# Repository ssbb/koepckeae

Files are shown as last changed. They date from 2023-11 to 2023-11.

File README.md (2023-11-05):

# koepckeae

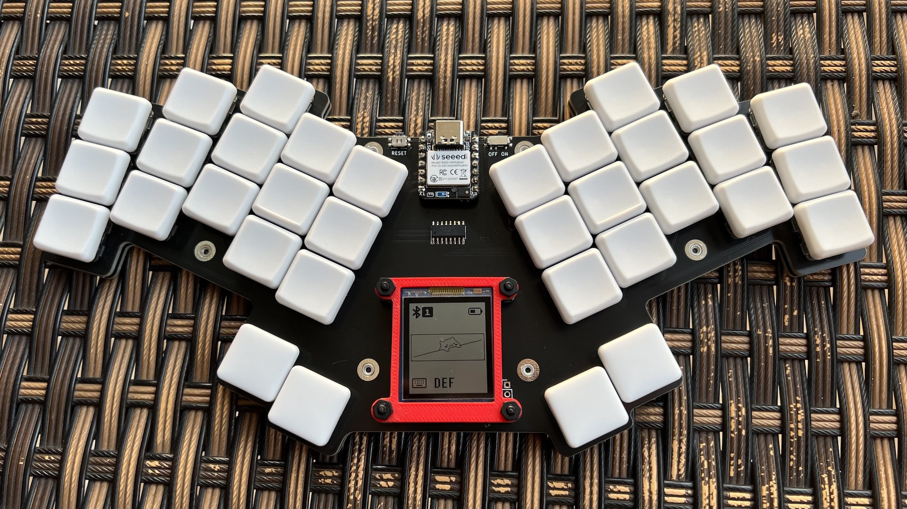
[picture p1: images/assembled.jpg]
PCB


koepckeae is a 34-key unibody split keyboard higihly inspired by Pete Johanson's [Zaphod Lite](https://gitlab.com/lpgalaxy/zaphod/-/tree/main), featuring hotswap support, splay, and spaced out thumbs.

## BOM

| Qty | Name | Source |
|-----|---|---|
| 1 | PCB | [gerbers](pcb/choc/koepckeae_gerbers.zip) |
| 1 | XIAO nRF52840 | [Digikey](https://www.digikey.com/en/products/detail/seeed-technology-co-ltd/102010448/16652893) |
| 1 | 74HC595D shift register (SOIC-16) | [LCSC](https://www.lcsc.com/product-detail/Shifting-Register_Nexperia-74HC595D-118_C5947.html) |
| 1 | PCM12 power switch | [LCSC](https://www.lcsc.com/product-detail/Slide-Switches_C-K-PCM12SMTR_C221841.html) |
| 1 | Panasonic EVQPUC02K reset button | [LCSC](https://www.lcsc.com/product-detail/_PANASONIC-_C79174.html) |
| 2 | 1x1 Mill-Max Spring Loaded Header (0906-2-15-20-75-14-11-0) | [Digikey](https://www.digikey.com/en/products/detail/mill-max-manufacturing-corp/0906-2-15-20-75-14-11-0/1147050)  |
| 2 | 1x7 Mill-Max Header (310-43-107-41-001000) | [Digikey](https://www.digikey.com/en/products/detail/mill-max-manufacturing-corp/310-43-107-41-001000/1212181) |
| 1 | JST PH-2.0 battery socket | [LCSC](https://www.lcsc.com/product-detail/Wire-To-Board-Wire-To-Wire-Connector_JST-S2B-PH-K-S-LF-SN_C173752.html) |
| 1 | 702025 300 mAh battery | |
| 34  | 1N4148W diode | [LCSC](https://www.lcsc.com/product-detail/Switching-Diode_MDD-Microdiode-Electronics-1N4148W_C84367.html) |
| 34  | Kailh Choc hotswap sockets | [Aliexpress](https://aliexpress.com/item/33023283633.html?sku_id=10000000883911874) |

Max battery dimensions are 29mm x 21mm x 8mm. Ideally get a battery with JST connector but double check polarity on PCB.

### Plate case

| Qty | Name | Source |
|-----|---|---|
| 1 | Bottom Plate | [gerbers](mechanical/bottom-plate/bottom_plate_gerbers.zip) |
| 8 | Solder Nuts  | [LCSC](https://www.lcsc.com/product-detail/_Sinhoo-_C2916384.html) |
| 8 | M2x5 screws  | |

### Display

| Qty | Name | Source |
|-----|---|---|
| 1 | Adafruit Sharp Memory Display | [Adafruit](https://www.adafruit.com/product/3502) |
| 1 | 1x5 Mill-Max Spring Loaded Header (825-22-005-10-001101) | [Digikey](https://www.digikey.com/en/products/detail/mill-max-manufacturing-corp/825-22-005-10-001101/6149696) |
| 4 | M2.5x6 male-female nylon standoff | [Aliexpress](https://aliexpress.com/item/32871403400.html?sku_id=10000002420611426) |
| 4 | M2.5 nylon nut | [Aliexpress](https://aliexpress.com/item/32868992270.html?sku_id=10000010058105677) |
| 4 | M2.5x6 nylon screw | [Aliexpress](https://aliexpress.com/item/32870030598.html?sku_id=10000002668418327) |

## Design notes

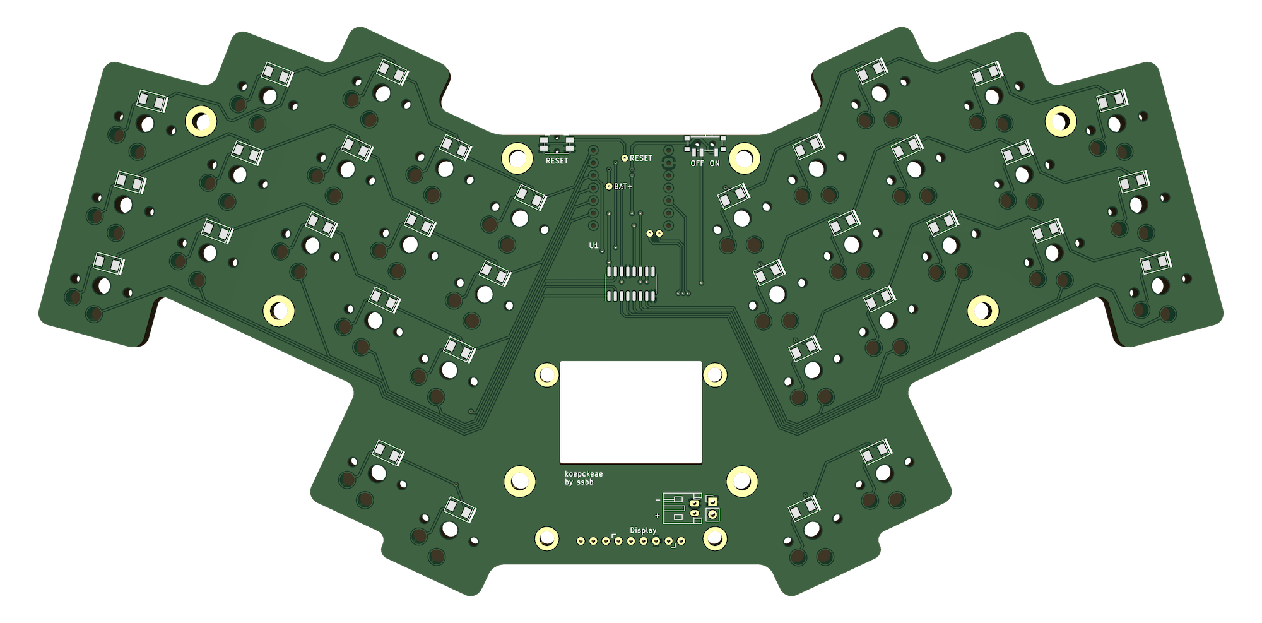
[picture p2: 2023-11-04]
images/pcb.png

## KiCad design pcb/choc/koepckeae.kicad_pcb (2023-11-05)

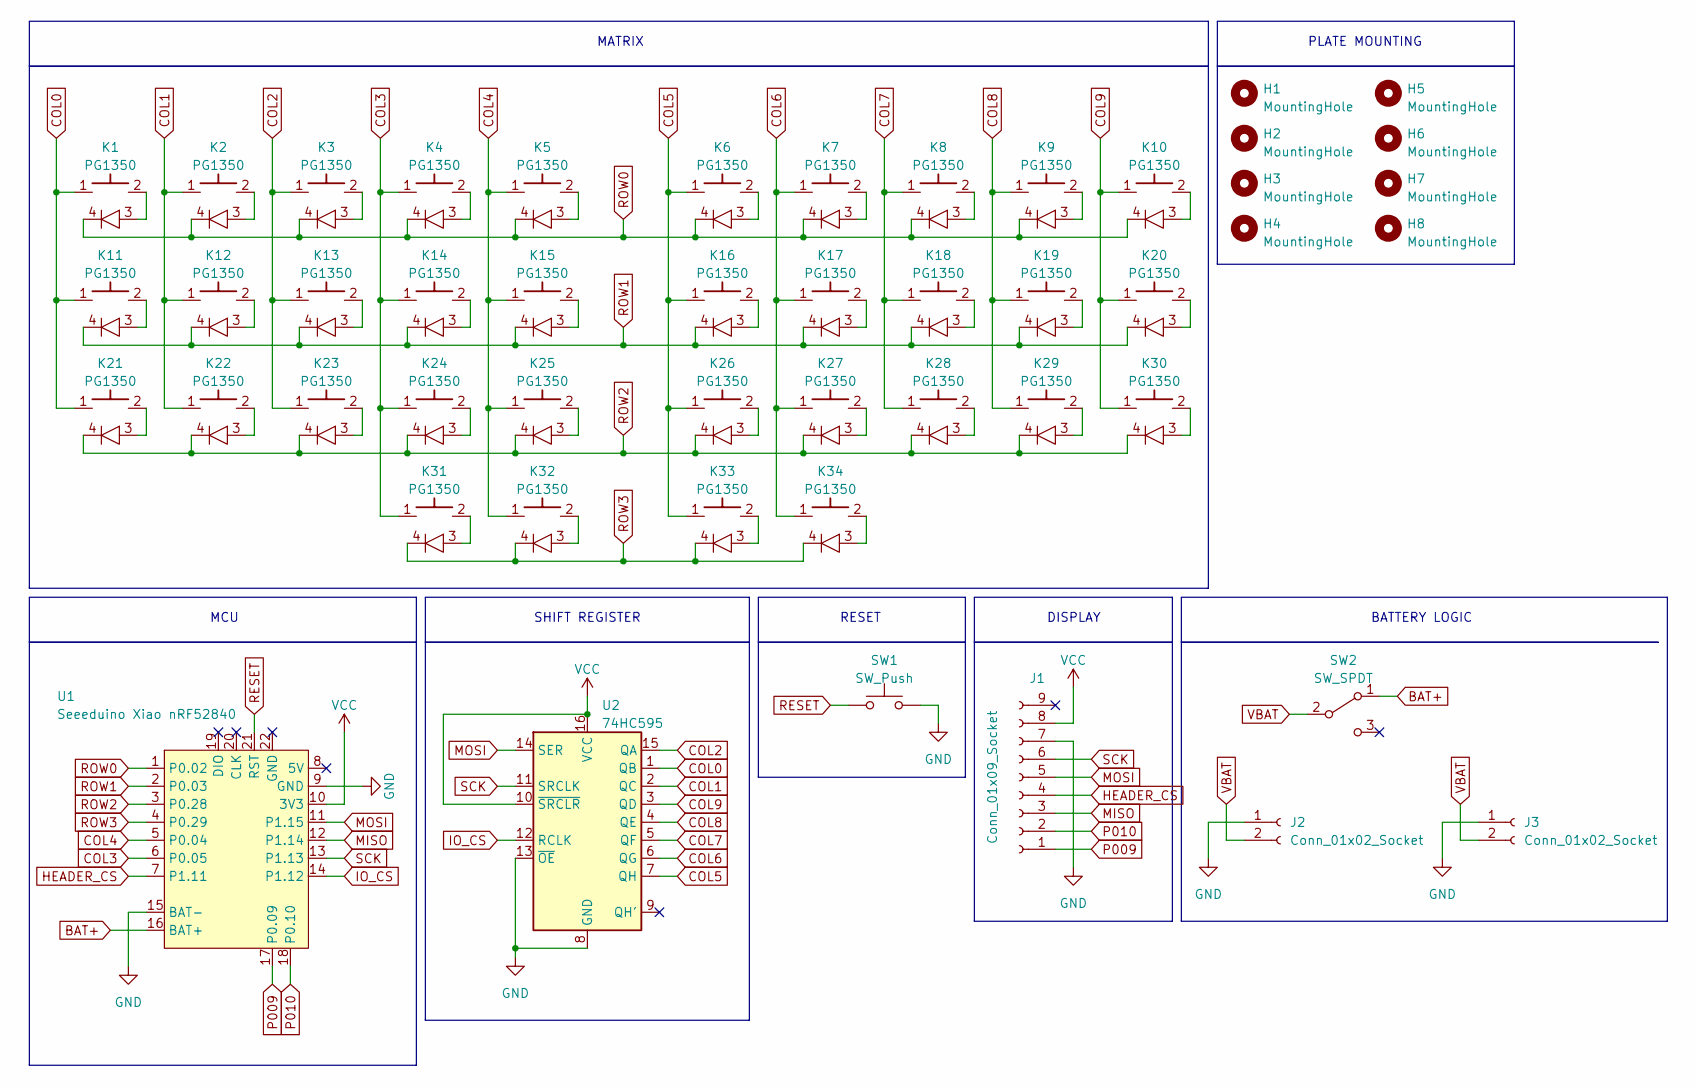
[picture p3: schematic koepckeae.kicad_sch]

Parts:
H1, H2, H3, H4, H5, H6, H7, H8: MountingHole
J1: Conn_01x09_Socket; Adafruit_Sharp_Memory_Display_1.3in
J2: Conn_01x02_Socket; PinHeader_1x02_P2.54mm_Vertical
J3: Conn_01x02_Socket; JST_PH_S2B-PH-K_1x02_P2.00mm_Horizontal
K1, K2, K3, K4, K5, K6, K7, K8, K9, K10, K11, K12, K13, K14, K15, K16, K17, K18, K19, K20, K21, K22, K23, K24, K25, K26, K27, K28, K29, K30, K31, K32, K33, K34: PG1350; PG1350_HS; LCSC C2099
SW1: SW_Push; Panasonic_EVQPUL_EVQPUC
SW2: SW_SPDT; SW_SPDT_PCM12
U1: Seeeduino Xiao nRF52840; Xiao_nRF52840_AH_Pogo
U2: 74HC595; SOIC-16_3.9x9.9mm_P1.27mm

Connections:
BAT+: SW2.1 (A), U1.16 (BAT+)
COL0: K1.1, K11.1, K21.1, U2.1 (QB)
COL1: K2.1, K12.1, K22.1, U2.2 (QC)
COL2: K3.1, K13.1, K23.1, U2.15 (QA)
COL3: K4.1, K14.1, K24.1, K31.1, U1.6 (P0.05)
COL4: K5.1, K15.1, K25.1, K32.1, U1.5 (P0.04)
COL5: K6.1, K16.1, K26.1, K33.1, U2.7 (QH)
COL6: K7.1, K17.1, K27.1, K34.1, U2.6 (QG)
COL7: K8.1, K18.1, K28.1, U2.5 (QF)
COL8: K9.1, K19.1, K29.1, U2.4 (QE)
COL9: K10.1, K20.1, K30.1, U2.3 (QD)
GND: J1.7, J2.1, J3.1, SW1.2, U1.9 (GND), U1.15 (BAT-), U2.8 (GND), U2.13 (~OE)
HEADER_CS: J1.4, U1.7 (P1.11)
IO_CS: U1.14 (P1.12), U2.12 (RCLK)
MISO: J1.3, U1.12 (P1.14)
MOSI: J1.5, U1.11 (P1.15), U2.14 (SER)
unnamed: K1.2, K1.3
unnamed: K2.2, K2.3
unnamed: K3.2, K3.3
unnamed: K4.2, K4.3
unnamed: K5.2, K5.3
unnamed: K6.2, K6.3
unnamed: K7.2, K7.3
unnamed: K8.2, K8.3
unnamed: K9.2, K9.3
unnamed: K10.2, K10.3
unnamed: K11.2, K11.3
unnamed: K12.2, K12.3
unnamed: K13.2, K13.3
unnamed: K14.2, K14.3
unnamed: K15.2, K15.3
unnamed: K16.2, K16.3
unnamed: K17.2, K17.3
unnamed: K18.2, K18.3
unnamed: K19.2, K19.3
unnamed: K20.2, K20.3
unnamed: K21.2, K21.3
unnamed: K22.2, K22.3
unnamed: K23.2, K23.3
unnamed: K24.2, K24.3
unnamed: K25.2, K25.3
unnamed: K26.2, K26.3
unnamed: K27.2, K27.3
unnamed: K28.2, K28.3
unnamed: K29.2, K29.3
unnamed: K30.2, K30.3
unnamed: K31.2, K31.3
unnamed: K32.2, K32.3
unnamed: K33.2, K33.3
unnamed: K34.2, K34.3
P009: J1.1, U1.17 (P0.09)
P010: J1.2, U1.18 (P0.10)
RESET: SW1.1, U1.21 (RST)
ROW0: K1.4, K2.4, K3.4, K4.4, K5.4, K6.4, K7.4, K8.4, K9.4, K10.4, U1.1 (P0.02)
ROW1: K11.4, K12.4, K13.4, K14.4, K15.4, K16.4, K17.4, K18.4, K19.4, K20.4, U1.2 (P0.03)
ROW2: K21.4, K22.4, K23.4, K24.4, K25.4, K26.4, K27.4, K28.4, K29.4, K30.4, U1.3 (P0.28)
ROW3: K31.4, K32.4, K33.4, K34.4, U1.4 (P0.29)
SCK: J1.6, U1.13 (P1.13), U2.11 (SRCLK)
VBAT: J2.2, J3.2, SW2.2 (B)
VCC: J1.8, U1.10 (3V3), U2.10 (~SRCLR), U2.16 (VCC)

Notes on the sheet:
MATRIX
SHIFT REGISTER
BATTERY LOGIC
PLATE MOUNTING
RESET
MCU
DISPLAY

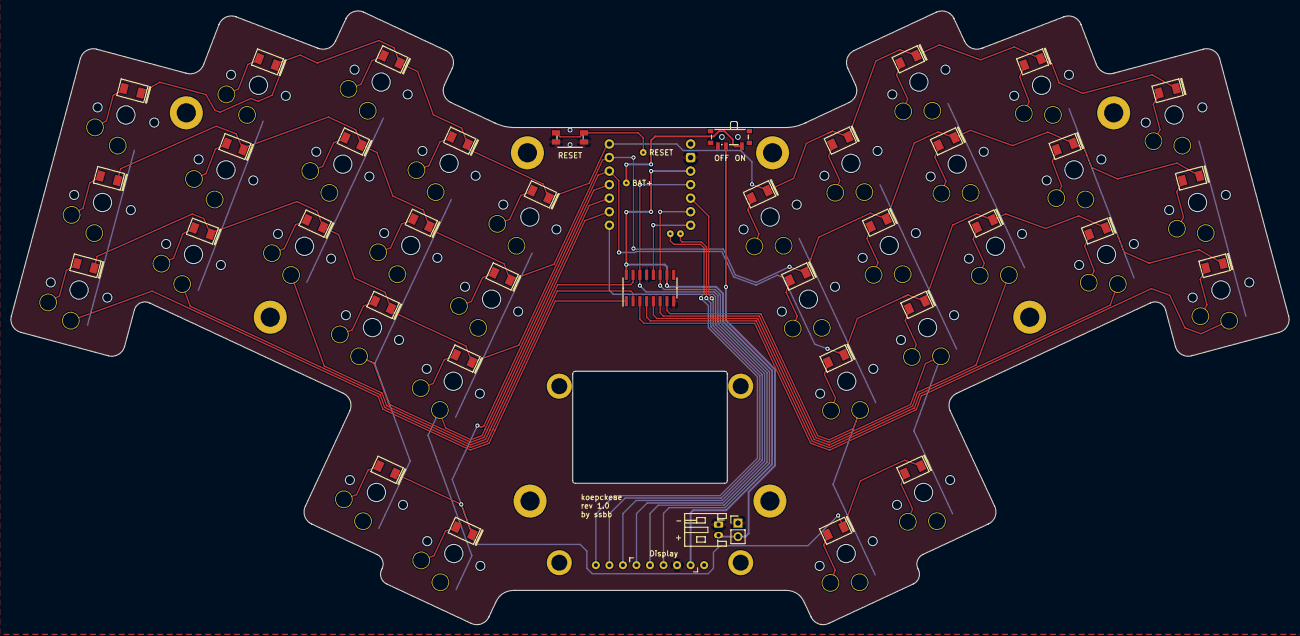
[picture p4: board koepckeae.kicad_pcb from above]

Board: 2 copper layers, 239.8 x 115.1 mm, 49 parts (0 on the bottom side), 60 nets.

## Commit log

2023-11-04 Move kicad libs into its own dir
2023-11-04 Remove unused fpc
    [koepckeae.kicad_pcb, koepckeae.kicad_sch]
2023-11-04 Add bottom plate gerbers
    [koepckeae.kicad_pcb]
2023-11-04 Add pcb gerbers
    [koepckeae.kicad_pcb]
2023-11-04 Test if markdewon links to gerbers are working
2023-11-04 Add simple bom
2023-11-04 Update BOM
2023-11-04 Remove u1 silk and re-generate gerbers
    [koepckeae.kicad_pcb]
2023-11-04 Make bom a bit more obvious
2023-11-04 Improve BOM
2023-11-04 Add intro
    [koepckeae.kicad_pcb]
2023-11-05 Add assembled photo
2023-11-05 Change fsilk label
    [koepckeae.kicad_pcb]
